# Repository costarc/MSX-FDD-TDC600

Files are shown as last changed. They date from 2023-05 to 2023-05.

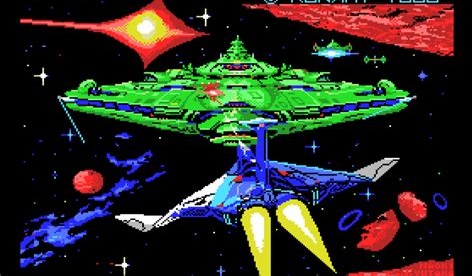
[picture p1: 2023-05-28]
Gradius-MSX.png

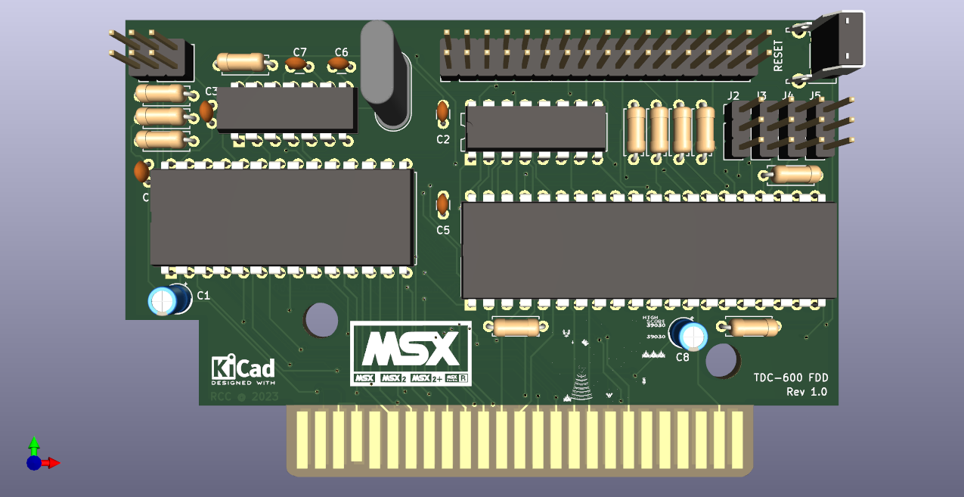
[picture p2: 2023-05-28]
TDC-600.png

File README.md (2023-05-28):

# MSX DC-600
Floppy Disk Controller for MSX nad MSX2 Computers.

Talent TDC-600 clone. PCB redrawn for fit to standard cartridge case.

DC-600
DC-600

### YouTube Video
YouTube link (https://www.youtube.com/watch?v=Oa3J1MnWHXI)# MSX-TDC-600

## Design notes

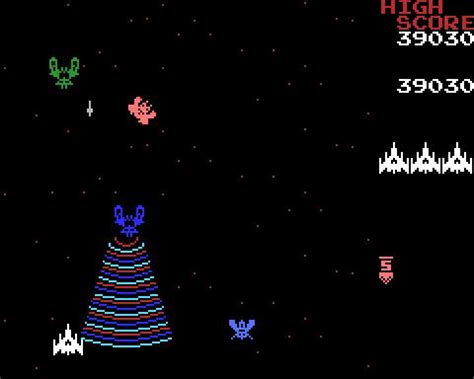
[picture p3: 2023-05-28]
galaga.png

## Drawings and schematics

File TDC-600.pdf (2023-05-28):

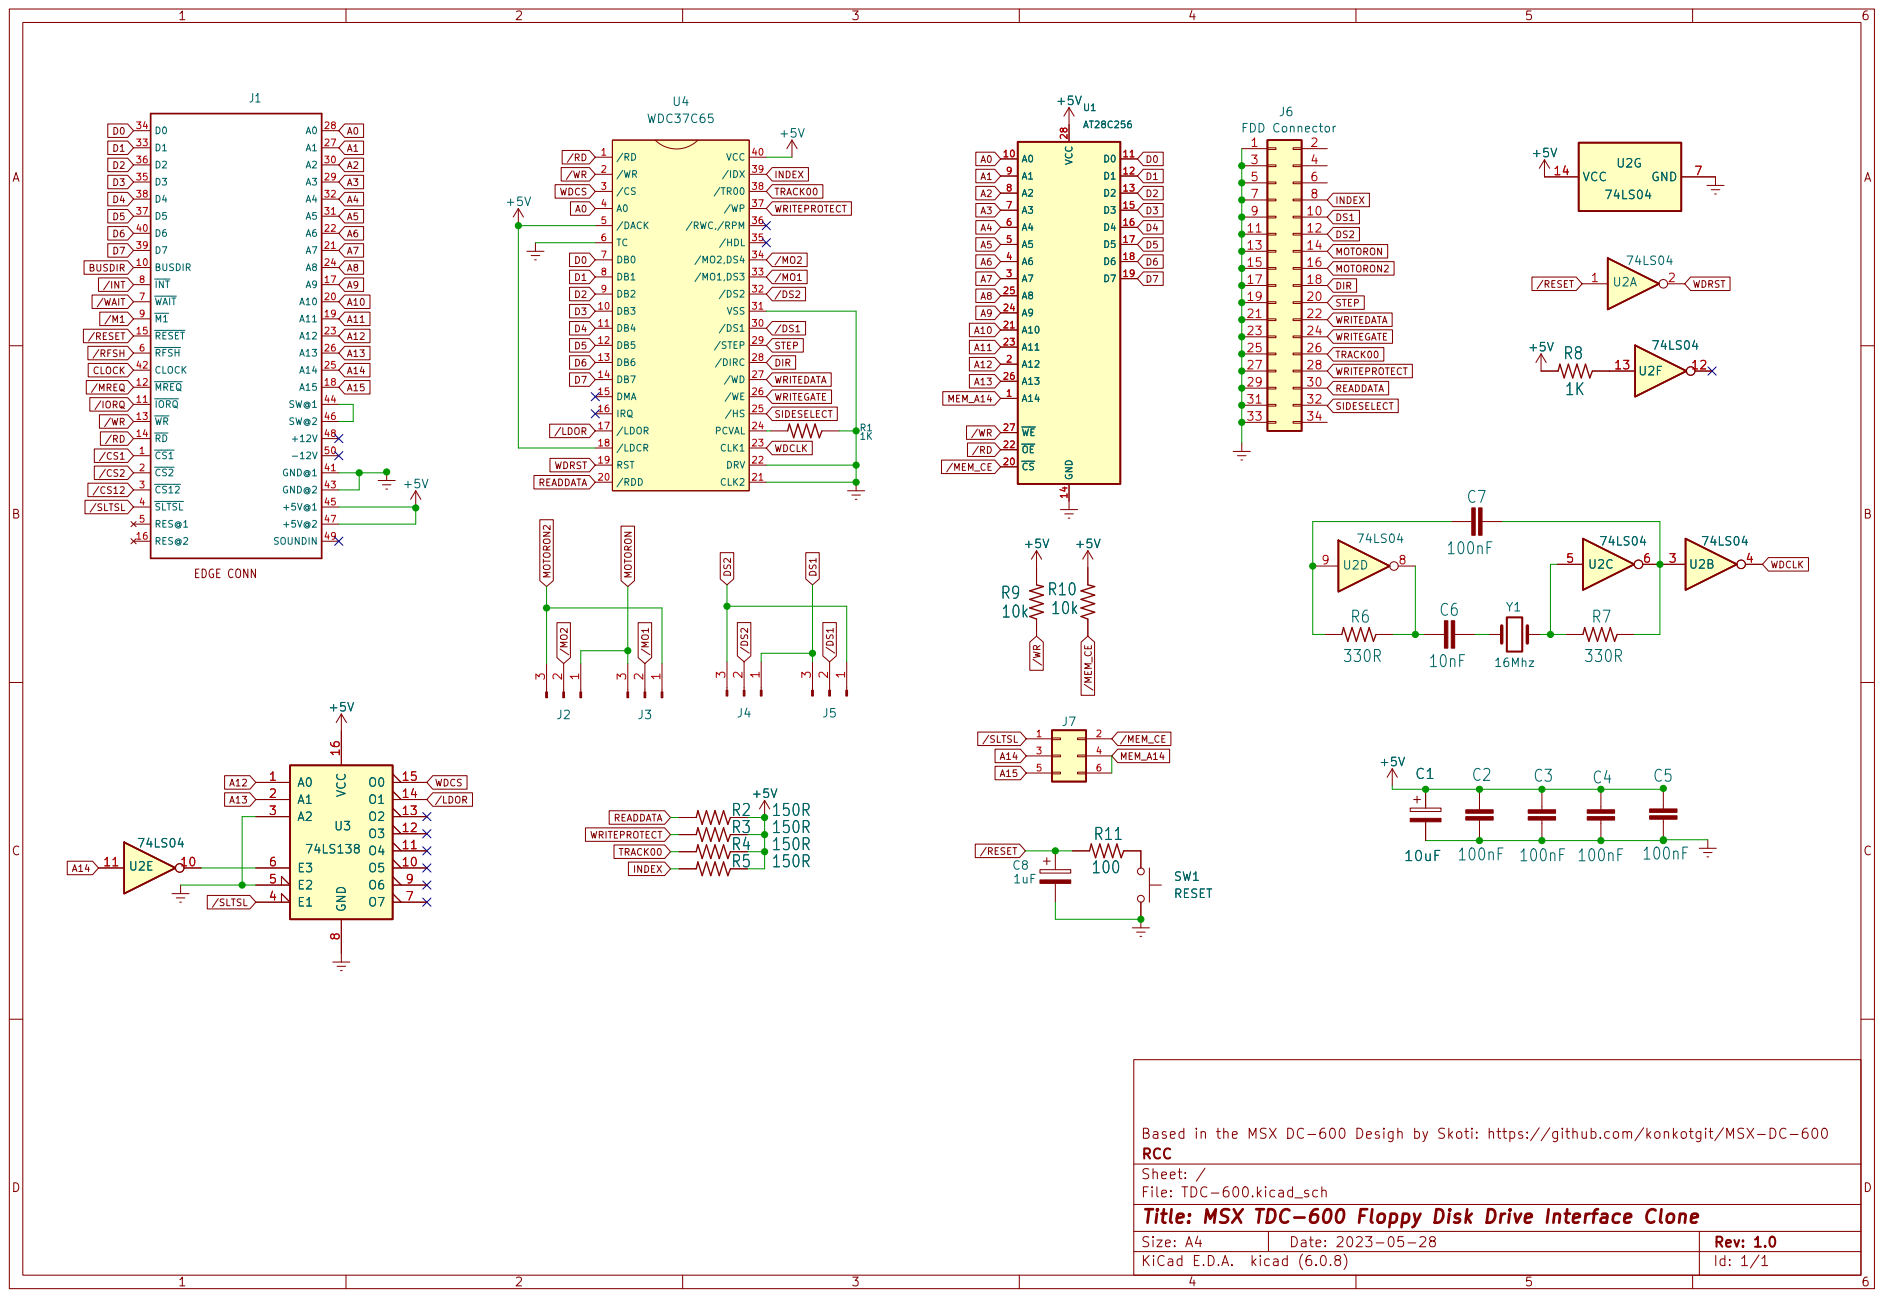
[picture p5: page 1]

9 | 10

Based in the MSX DC-600 Desigh by Skoti: https://github.com/konkotgit/MSX-DC-600
File: TDC-600.kicad_sch Sheet: / RCC

Id: 1/1 Title: MSX TDC-600 Floppy Disk Drive Interface Clone

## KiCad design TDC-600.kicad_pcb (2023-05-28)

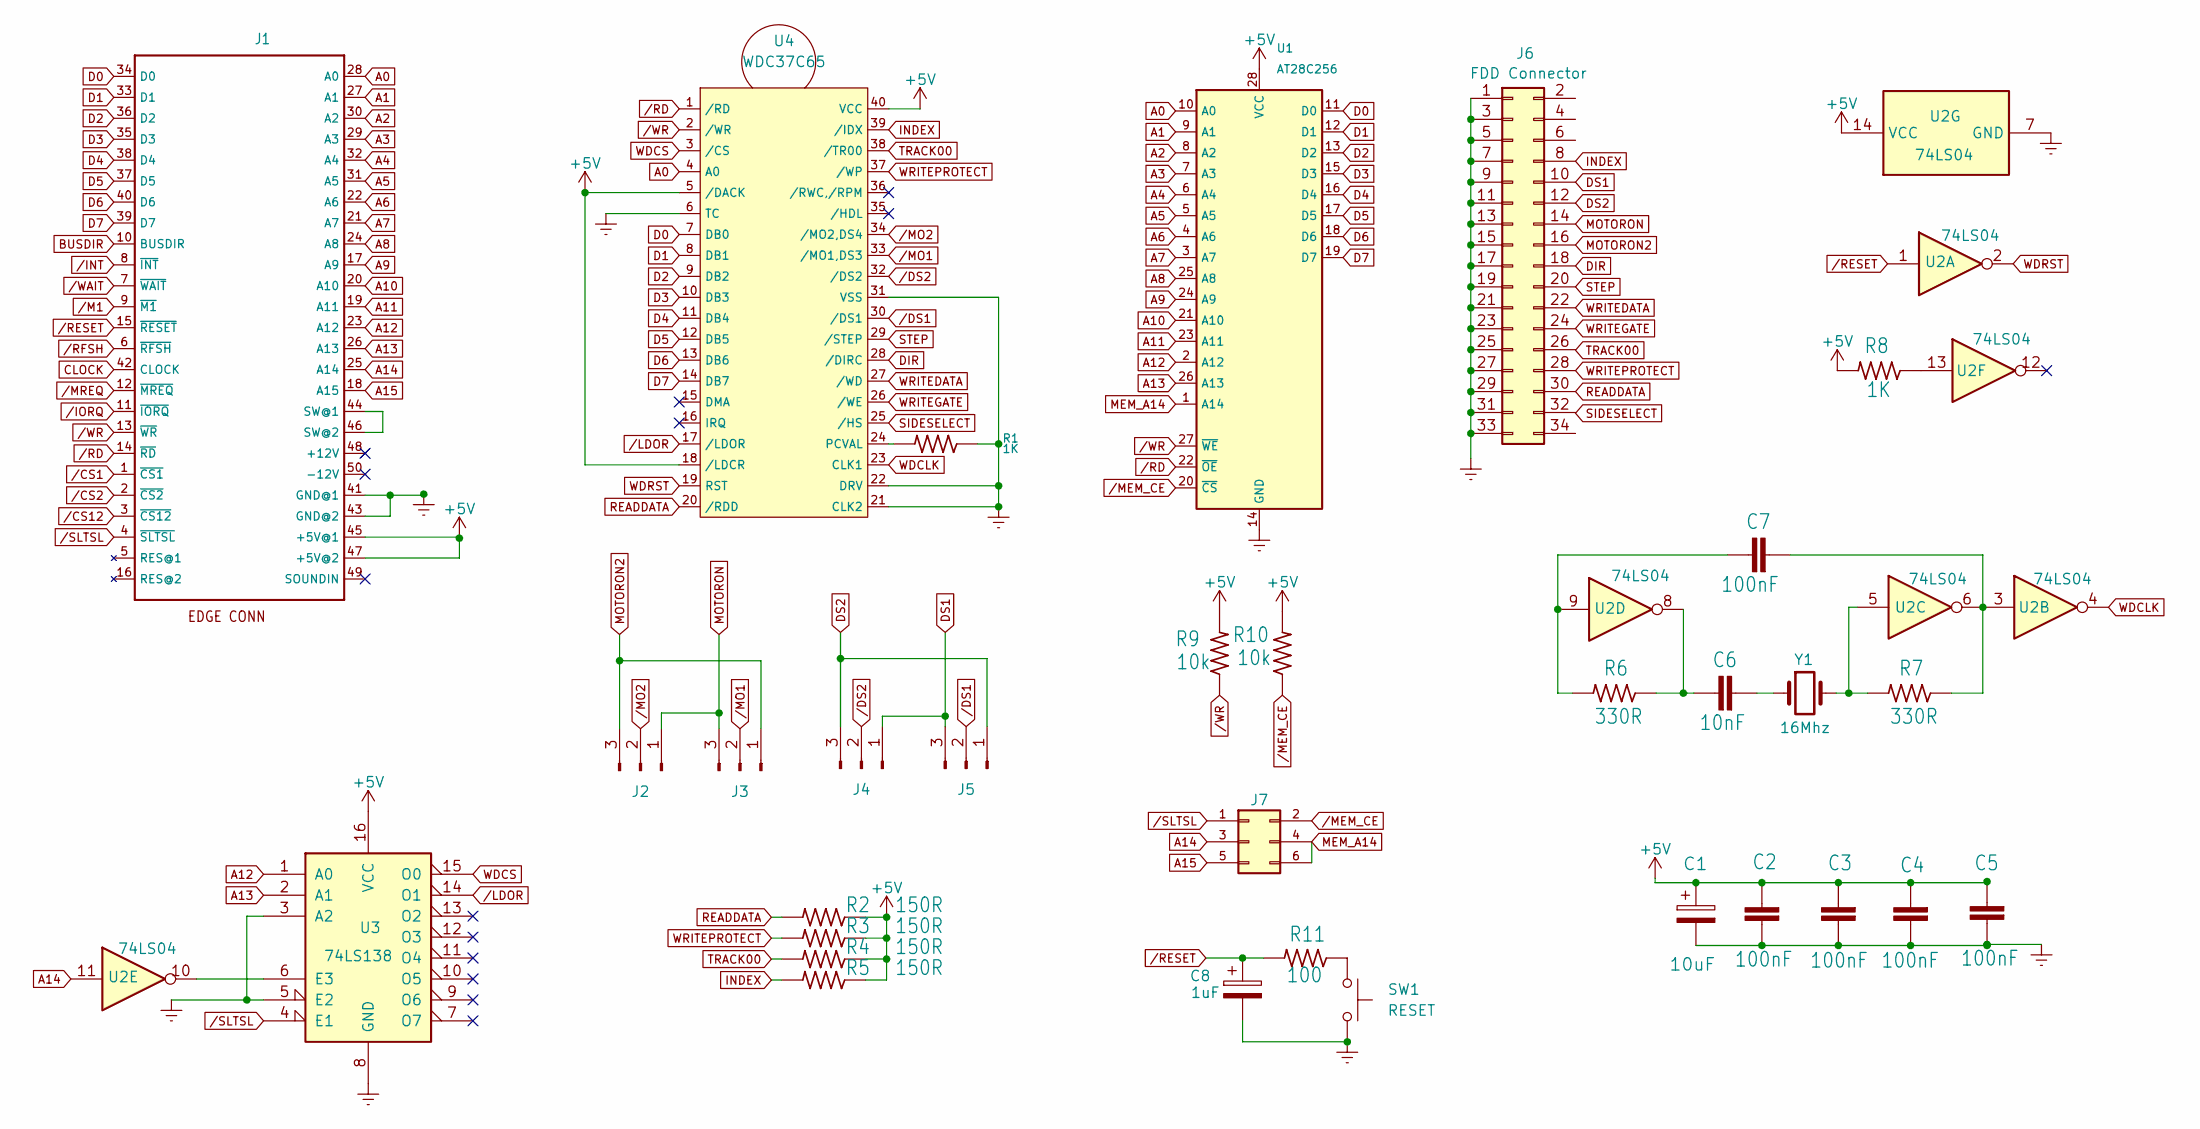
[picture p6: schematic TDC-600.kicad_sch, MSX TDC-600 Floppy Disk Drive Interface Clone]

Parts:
C1: 10uF; CP_Radial_D4.0mm_P1.50mm
C2, C3, C4, C5, C7: 100nF; C_Disc_D3.0mm_W1.6mm_P2.50mm
C6: 10nF; C_Disc_D3.0mm_W1.6mm_P2.50mm
C8: 1uF; CP_Radial_D4.0mm_P1.50mm
J1: MSXCART1; MSX_CART_SW_Official
J2, J3, J4, J5: Conn_01x03_Male; PinHeader_1x03_P2.54mm_Vertical
J6: FDD Connector; PinHeader_2x17_P2.54mm_Vertical
J7: ROM_SWITCH; PinHeader_2x03_P2.54mm_Vertical
R1, R8: 1K; R_Axial_DIN0207_L6.3mm_D2.5mm_P7.62mm_Horizontal
R2, R3, R4, R5: 150R; R_Axial_DIN0207_L6.3mm_D2.5mm_P7.62mm_Horizontal
R6, R7: 330R; R_Axial_DIN0207_L6.3mm_D2.5mm_P7.62mm_Horizontal
R9, R10: 10k; R_Axial_DIN0207_L6.3mm_D2.5mm_P7.62mm_Horizontal
R11: 100; R_Axial_DIN0207_L6.3mm_D2.5mm_P7.62mm_Horizontal
SW1: RESET; SW_Tactile_SPST_Angled_PTS645Vx31-2LFS
U1: AT28C256; DIP-28_W15.24mm
U2: 74LS04; DIP-14_W7.62mm
U3: 74LS138; DIP-16_W7.62mm
U4: WDC37C65; DIP-40_W15.24mm
Y1: 16Mhz; Crystal_HC49-U_Vertical

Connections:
+5V: C1.1, C2.2, C3.2, C4.2, C5.2, J1.45 (+5V@1), J1.47 (+5V@2), R2.1, R3.1, R4.1, R5.1, R8.2, R9.2, R10.2, U1.28 (VCC), U2.14 (VCC), U3.16 (VCC), U4.5 (/DACK), U4.18 (/LDCR), U4.40 (VCC)
A0: J1.28 (A0), U1.10 (A0), U4.4 (A0)
A1: J1.27 (A1), U1.9 (A1)
A2: J1.30 (A2), U1.8 (A2)
A3: J1.29 (A3), U1.7 (A3)
A4: J1.32 (A4), U1.6 (A4)
A5: J1.31 (A5), U1.5 (A5)
A6: J1.22 (A6), U1.4 (A6)
A7: J1.21 (A7), U1.3 (A7)
A8: J1.24 (A8), U1.25 (A8)
A9: J1.17 (A9), U1.24 (A9)
A10: J1.20 (A10), U1.21 (A10)
A11: J1.19 (A11), U1.23 (A11)
A12: J1.23 (A12), U1.2 (A12), U3.1 (A0)
A13: J1.26 (A13), U1.26 (A13), U3.2 (A1)
A14: J1.25 (A14), J7.3, U2.11
A15: J1.18 (A15), J7.5
BUSDIR: J1.10 (BUSDIR)
CLOCK: J1.42 (CLOCK)
D0: J1.34 (D0), U1.11 (D0), U4.7 (DB0)
D1: J1.33 (D1), U1.12 (D1), U4.8 (DB1)
D2: J1.36 (D2), U1.13 (D2), U4.9 (DB2)
D3: J1.35 (D3), U1.15 (D3), U4.10 (DB3)
D4: J1.38 (D4), U1.16 (D4), U4.11 (DB4)
D5: J1.37 (D5), U1.17 (D5), U4.12 (DB5)
D6: J1.40 (D6), U1.18 (D6), U4.13 (DB6)
D7: J1.39 (D7), U1.19 (D7), U4.14 (DB7)
DIR: J6.18, U4.28 (/DIRC)
DS1: J4.1, J5.3, J6.10
DS2: J4.3, J5.1, J6.12
GNDREF: C1.2, C2.1, C3.1, C4.1, C5.1, C8.2, J1.41 (GND@1), J1.43 (GND@2), J6.1, J6.3, J6.5, J6.7, J6.9, J6.11, J6.13, J6.15, J6.17, J6.19, J6.21, J6.23, J6.25, J6.27, J6.29, J6.31, J6.33, R1.1, SW1.2, U1.14 (GND), U2.7 (GND), U3.3 (A2), U3.5 (E2), U3.8 (GND), U4.6 (TC), U4.21 (CLK2), U4.22 (DRV), U4.31 (VSS)
INDEX: J6.8, R5.2, U4.39 (/IDX)
MEM_A14: J7.4, J7.6, U1.1 (A14)
MOTORON: J2.1, J3.3, J6.14
MOTORON2: J2.3, J3.1, J6.16
unnamed: C6.1, R6.1, U2.8
unnamed: C6.2, Y1.1
unnamed: C7.1, R6.2, U2.9
unnamed: C7.2, R7.1, U2.3, U2.6
unnamed: J1.44 (SW@1), J1.46 (SW@2)
unnamed: R1.2, U4.24 (PCVAL)
unnamed: R7.2, U2.5, Y1.2
unnamed: R8.1, U2.13
unnamed: R11.1, SW1.1
unnamed: U2.10, U3.6 (E3)
READDATA: J6.30, R2.2, U4.20 (/RDD)
SIDESELECT: U4.25 (/HS)
STEP: J6.20, U4.29 (/STEP)
TRACK00: R4.2, U4.38 (/TR00)
WDCLK: U2.4, U4.23 (CLK1)
WDCS: U3.15 (O0), U4.3 (/CS)
WDRST: U2.2, U4.19 (RST)
WRITEDATA: J6.22, U4.27 (/WD)
WRITEGATE: U4.26 (/WE)
WRITEPROTECT: J6.28, R3.2, U4.37 (/WP)
/CS1: J1.1 (~CS1)
/CS2: J1.2 (~CS2)
/CS12: J1.3 (~CS12)
/DS1: J5.2, U4.30 (/DS1)
/DS2: J4.2, U4.32 (/DS2)
/INT: J1.8 (~INT)
/IORQ: J1.11 (~IORQ)
/LDOR: U3.14 (O1), U4.17 (/LDOR)
/M1: J1.9 (~M1)
/MEM_CE: J7.2, R10.1, U1.20 (~CS)
/MO1: J3.2, U4.33 (/MO1,DS3)
/MO2: J2.2, U4.34 (/MO2,DS4)
/MREQ: J1.12 (~MREQ)
/RD: J1.14 (~RD), U1.22 (~OE), U4.1 (/RD)
/RESET: C8.1, J1.15 (~RESET), R11.2, U2.1
/RFSH: J1.6 (~RFSH)
/SLTSL: J1.4 (~SLTSL), J7.1, U3.4 (E1)
/WAIT: J1.7 (~WAIT)
/WR: J1.13 (~WR), R9.1, U1.27 (~WE), U4.2 (/WR)

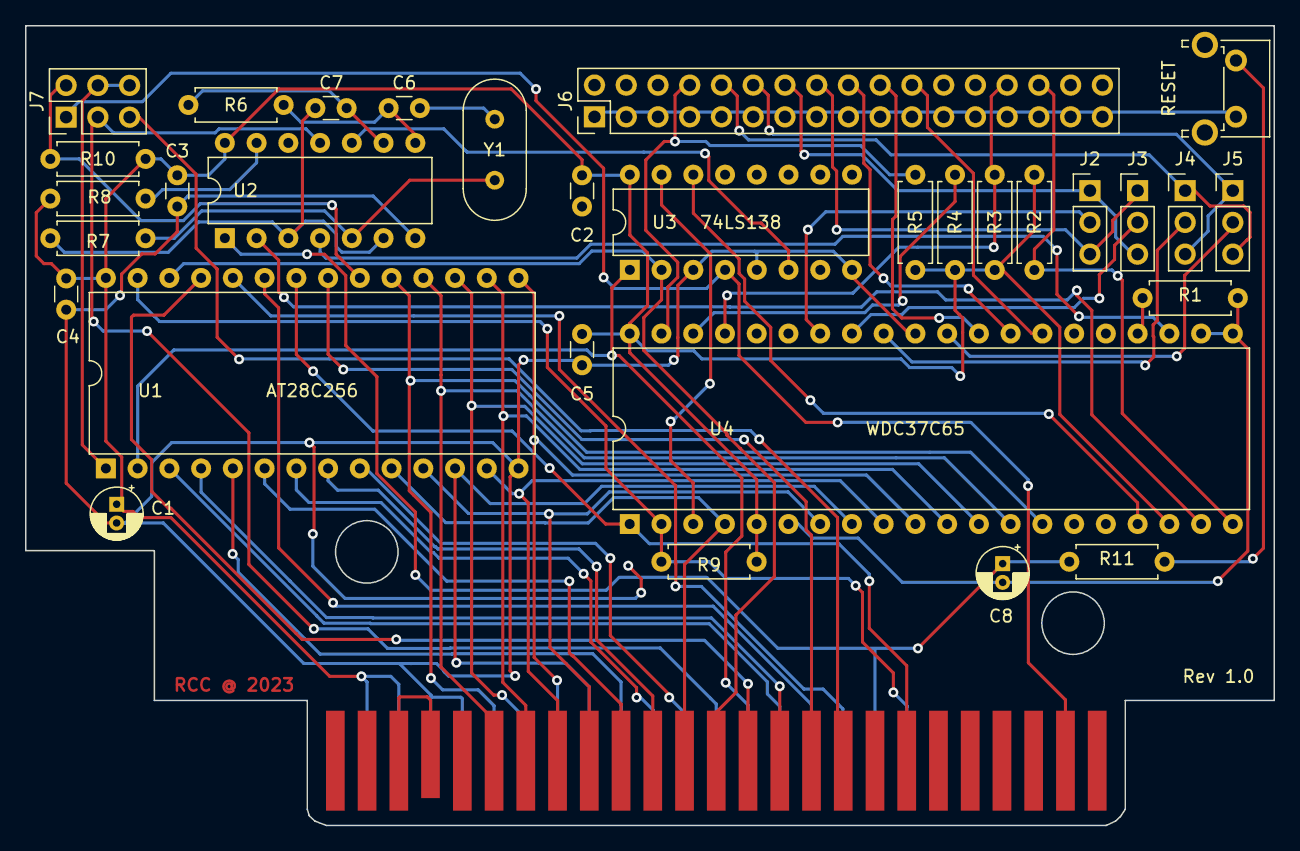
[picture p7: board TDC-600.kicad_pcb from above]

Board: 2 copper layers, 99.9 x 64.0 mm, 32 parts (0 on the bottom side), 61 nets.

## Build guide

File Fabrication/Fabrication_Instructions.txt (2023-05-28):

These instrucstions are for PCBWAY.COM
The lines with "=>" are the only ones that must ne changed - the others are default for PCBWAY.

The defaults will work very well, but I recommend to change "Edge Connector" option - see below.
These instructions will result in the cheapest cost (around USD5 for 5 Units)

=> Lenght: 99.90mm, Width: 64.50mm
Layers: 2, Thickness: 1.6mm
Material: FR-4
FR4-TG: TG 150-160
Thickness: 1.6
Min Track/Spacing: 6/6mil
Min Hole Size: 0.3mm
Solder Mask: -> choose what you like, but some places charge more for this option.
Silkscreen: White (change this color if you choose "White Solder Mask")
=> Edge connector: Yes, Bevelling: Yes - 30 Degrees
=> Surface Finish: HASL lead free (change to "immersion gold" at extra cost)

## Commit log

2023-05-28 Initial Redisgn Release 1.0
    [TDC-600.kicad_pcb, TDC-600.kicad_sch]
2023-05-28 Routing Release 1.0
    [TDC-600.kicad_pcb, TDC-600.kicad_sch]
2023-05-28 Routing complete for Rev 1.0
    [TDC-600.kicad_pcb, TDC-600.kicad_sch]
2023-05-28 ~Routing completed, gerbers generated
    [TDC-600.kicad_sch]
